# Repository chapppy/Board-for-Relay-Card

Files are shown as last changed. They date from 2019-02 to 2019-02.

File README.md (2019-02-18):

#  Board-for-Relay-Card
This repository contains design of schematic and PCB for Relay Card. 
**This board support**:
- up to 7 relays (with SPDT contacts)
- additional 7 relays on extra board
- control of relay over USB
- control of relay over CAN
- single power supply from USB
- possibility of external power supply (for board control over CAN)

This is based on STM32 microcontroller F0 family (STM32F072C8T6). This microcontroller supports USB and in advance it support crystal-less USB. The CAN driver is also available. 

The goal is use as less parts as possible with consideration of hand soldering. All the part should be simple to get or replace with another compatible. The design is simple two layer board with most of the parts (and all necessary) on top layer. The design fits to box for DIN lath.

This is related to these repositories:
[Firmware-for-Relay-Card](https://github.com/chapppy/Firmware-for-Relay-Card "Firmware-for-Relay-Card") 
[Sample-GUI-for-Relay-Card](https://github.com/chapppy/Sample-GUI-for-Relay-Card "Sample-GUI-for-Relay-Card")
[Board-for-Relay-Card](https://github.com/chapppy/Board-for-Relay-Card "Board-for-Relay-Card")

## schematic
[full schematic](https://github.com/chapppy/Board-for-Relay-Card/blob/master/export/schematic-full.pdf "full schematic")

In case of control only over USB and 4 relays, there is reduced schematic:
[reduced schematic](https://github.com/chapppy/Board-for-Relay-Card/blob/master/export/schematic-USB-4-rleays.pdf "reduced schematic")

## PCB design
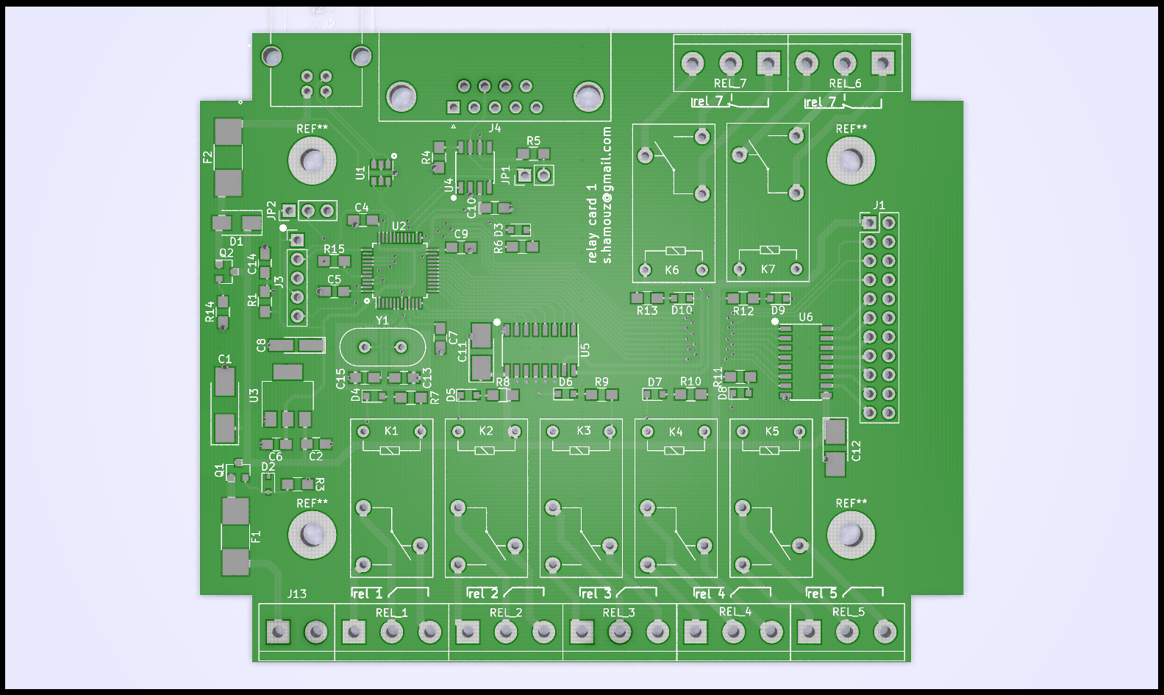
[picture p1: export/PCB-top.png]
PCB-top

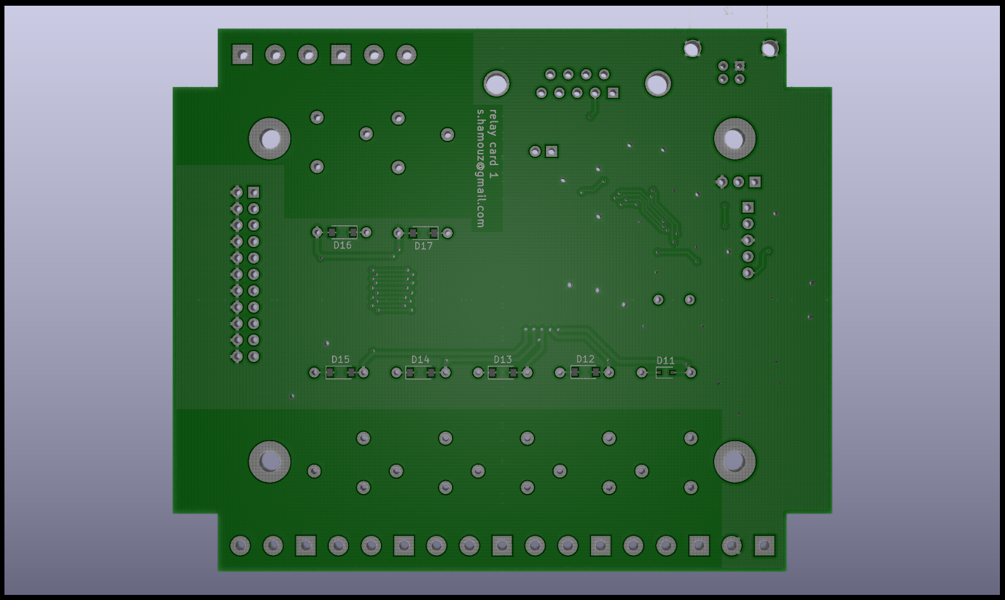
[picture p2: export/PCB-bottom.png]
PCB-bottom


## data for manufacturing
[manufacturing data](https://github.com/chapppy/Board-for-Relay-Card/blob/master/export/manufacturing.zip "manufacturing data")

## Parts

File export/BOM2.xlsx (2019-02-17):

quantity | Supplier ref | Link | Designation
8 | 1181041 | https://cz.farnell.com/omron/g5q-1eu-5dc/relay-spdt-250vac-30vdc-10a/dp/1181041 | G5SB-5V
2 | 2112373 | https://cz.farnell.com/multicomp/usb-b-s-ra/usb-2-0-type-b-receptacle-th/dp/2112373 | USB_B
8 | 1581242 | https://cz.farnell.com/multicomp/mcl-s270gc/led-0805-green-10mcd-570nm/dp/1581242 | LED
4 | 498737 | https://cz.farnell.com/avx/tajb106k016rnj/cap-10-f-16v-10-1210-smd/dp/498737 | 10uF/16V
2 | 2750643 | https://cz.farnell.com/stmicroelectronics/stm32f072c8t6/mcu-arm-cortex-m0-48mhz-lqfp-48/dp/2750643 | STM32F042C4Tx
2 | 2852737 | https://cz.farnell.com/avx/tajc476k016snj/cap-47-f-16v-10/dp/2852737 | 47uF/16V
2 | 2321203 | https://cz.farnell.com/kemet/t491a225k006at/cap-2-2-f-6-3v-10-1206/dp/2321203 | 2.2uF/6.3V
2 | 2317476 | https://cz.farnell.com/on-semiconductor/mm3z5v1st1g/diode-zener-5-1v-200mw-sod-323/dp/2317476 | 5v1
4 | 2468051 | https://cz.farnell.com/infineon/irlml2244trpbf/mosfet-p-ch-20v-4-3a-sot-23-3/dp/2468051 | IRLML6402TRPBF
2 | 1269406 | https://cz.farnell.com/stmicroelectronics/usblc6-2sc6/esd-protection-3-5pf-17v-sot23/dp/1269406 | USBLC6-2SC6
5 | 2510222 | https://cz.farnell.com/microchip/mic5205-3-3ym5-tr/ic-ldo-150ma-3-3v-ln-sot23-5/dp/2510222 | MIC5205-3.3
2 | 1842268 | https://cz.farnell.com/txc/9b-8-000maaj-b/xtal-8-000mhz-18pf-hc-49s/dp/1842268 | 8MHz
2 | 9907491 | https://cz.farnell.com/stmicroelectronics/stps1l30a/diode-schottky-1a-30v/dp/9907491 | STPS1L30A
4 | 2335704 | https://cz.farnell.com/texas-instruments/uln2003lvdr/relay-driver-sink-0-14a-soic-16/dp/2335704 | ULN2003A
2 | 1345924 | https://cz.farnell.com/littelfuse/minismdc075f-24-2/polyswitch-smd-1812-0-75a/dp/1345924 | SD110-16
2 | 1207268 | https://cz.farnell.com/texas-instruments/sn65hvd233dg4/transceiver-can-65hvd233-soic8/dp/1207268 | sn65hvd233
8 | 8734275 | https://cz.farnell.com/nexperia/bas316-115/diode-switching-250ma-100v-sod/dp/8734275 | D
2 | 2980894 | https://cz.farnell.com/stmicroelectronics/stm32g071gbu6/mcu-32bit-64mhz-ufqfpn-28/dp/2980894 | STM32G071GBU6

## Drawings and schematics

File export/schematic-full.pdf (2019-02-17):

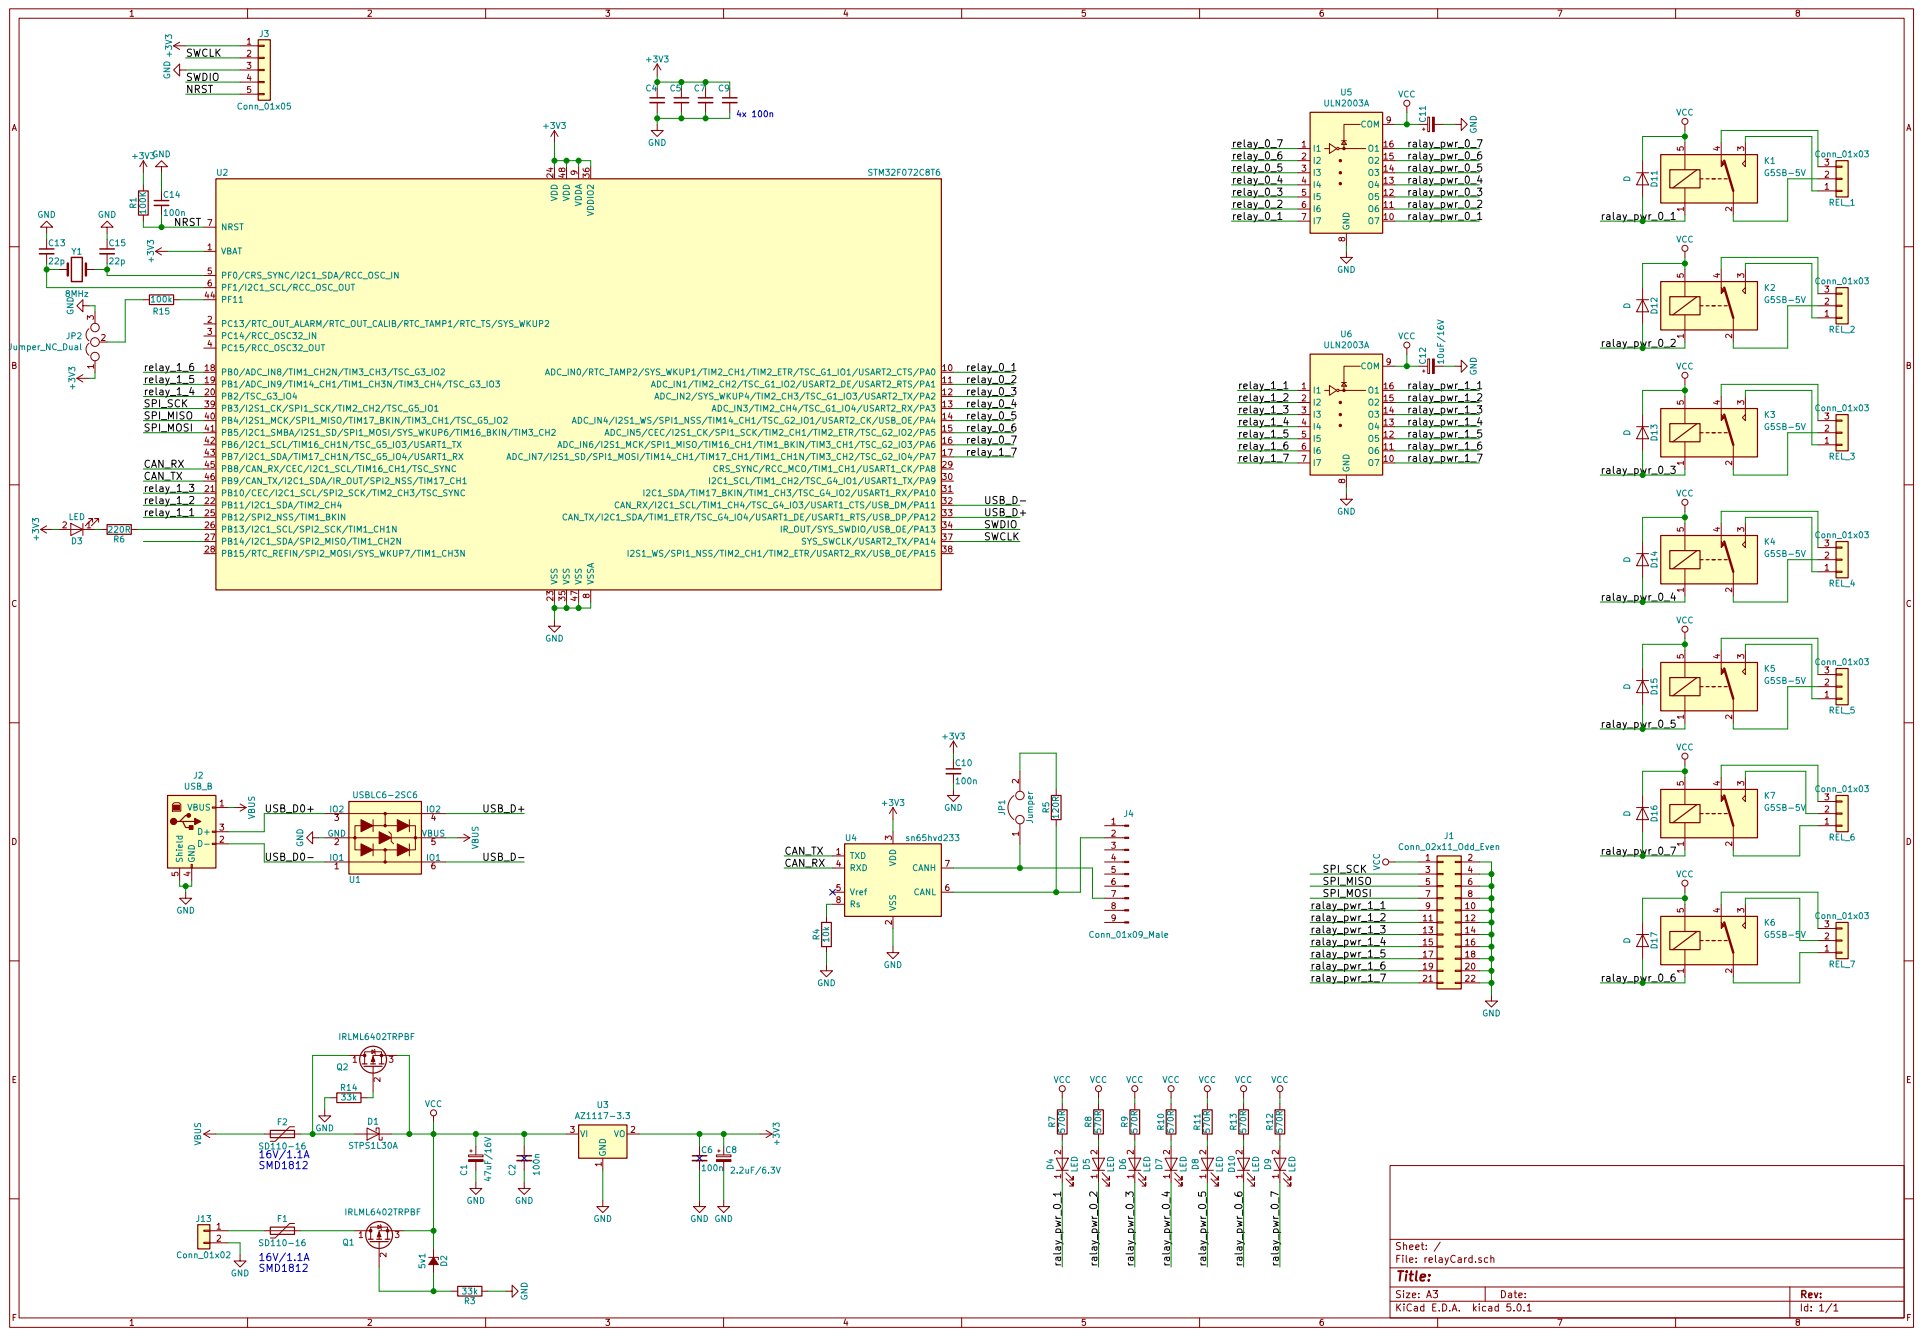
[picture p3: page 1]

File: relayCard.sch Sheet: /

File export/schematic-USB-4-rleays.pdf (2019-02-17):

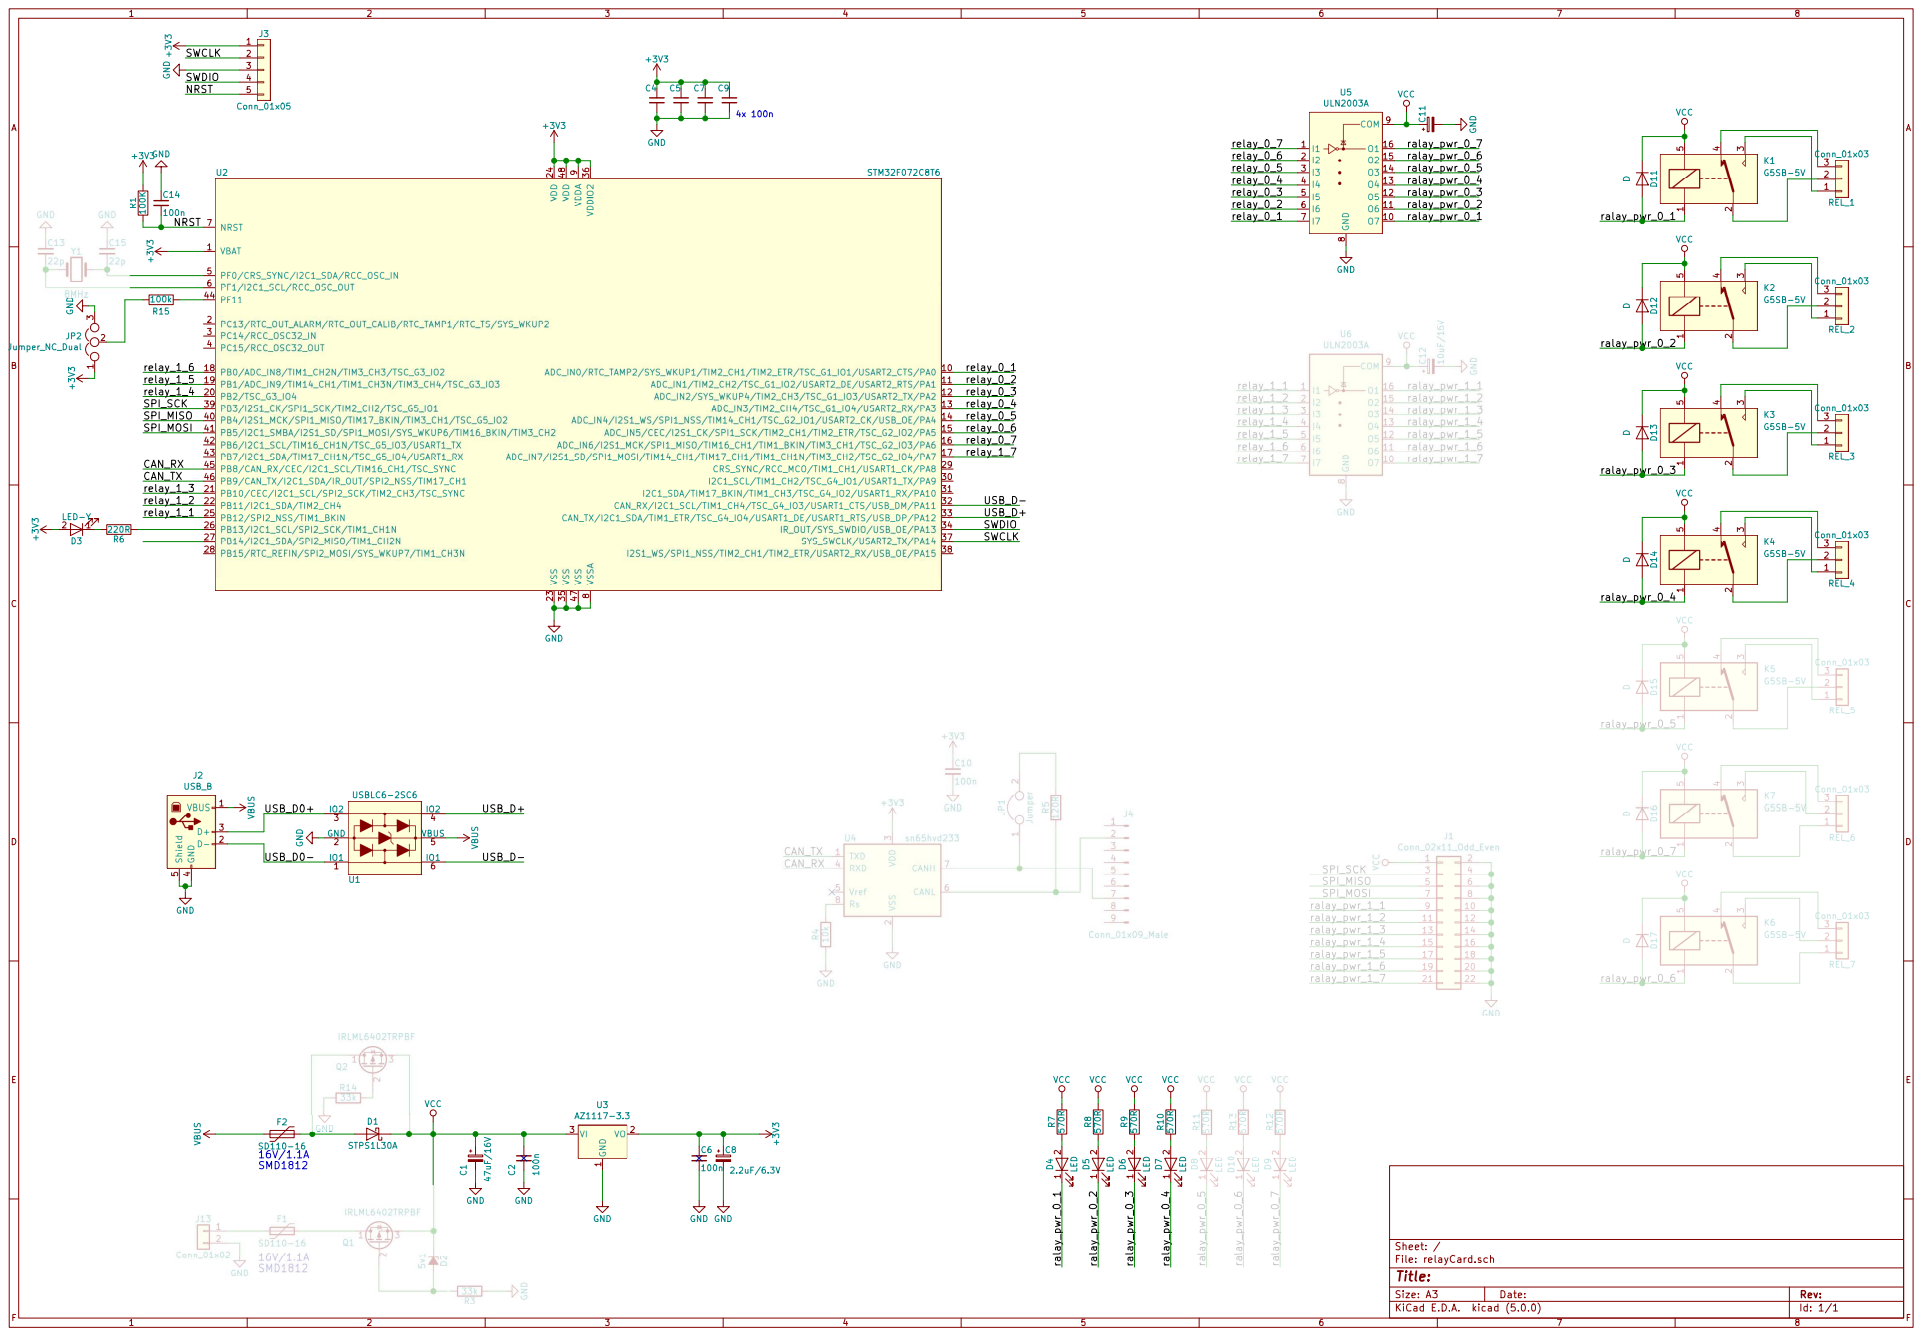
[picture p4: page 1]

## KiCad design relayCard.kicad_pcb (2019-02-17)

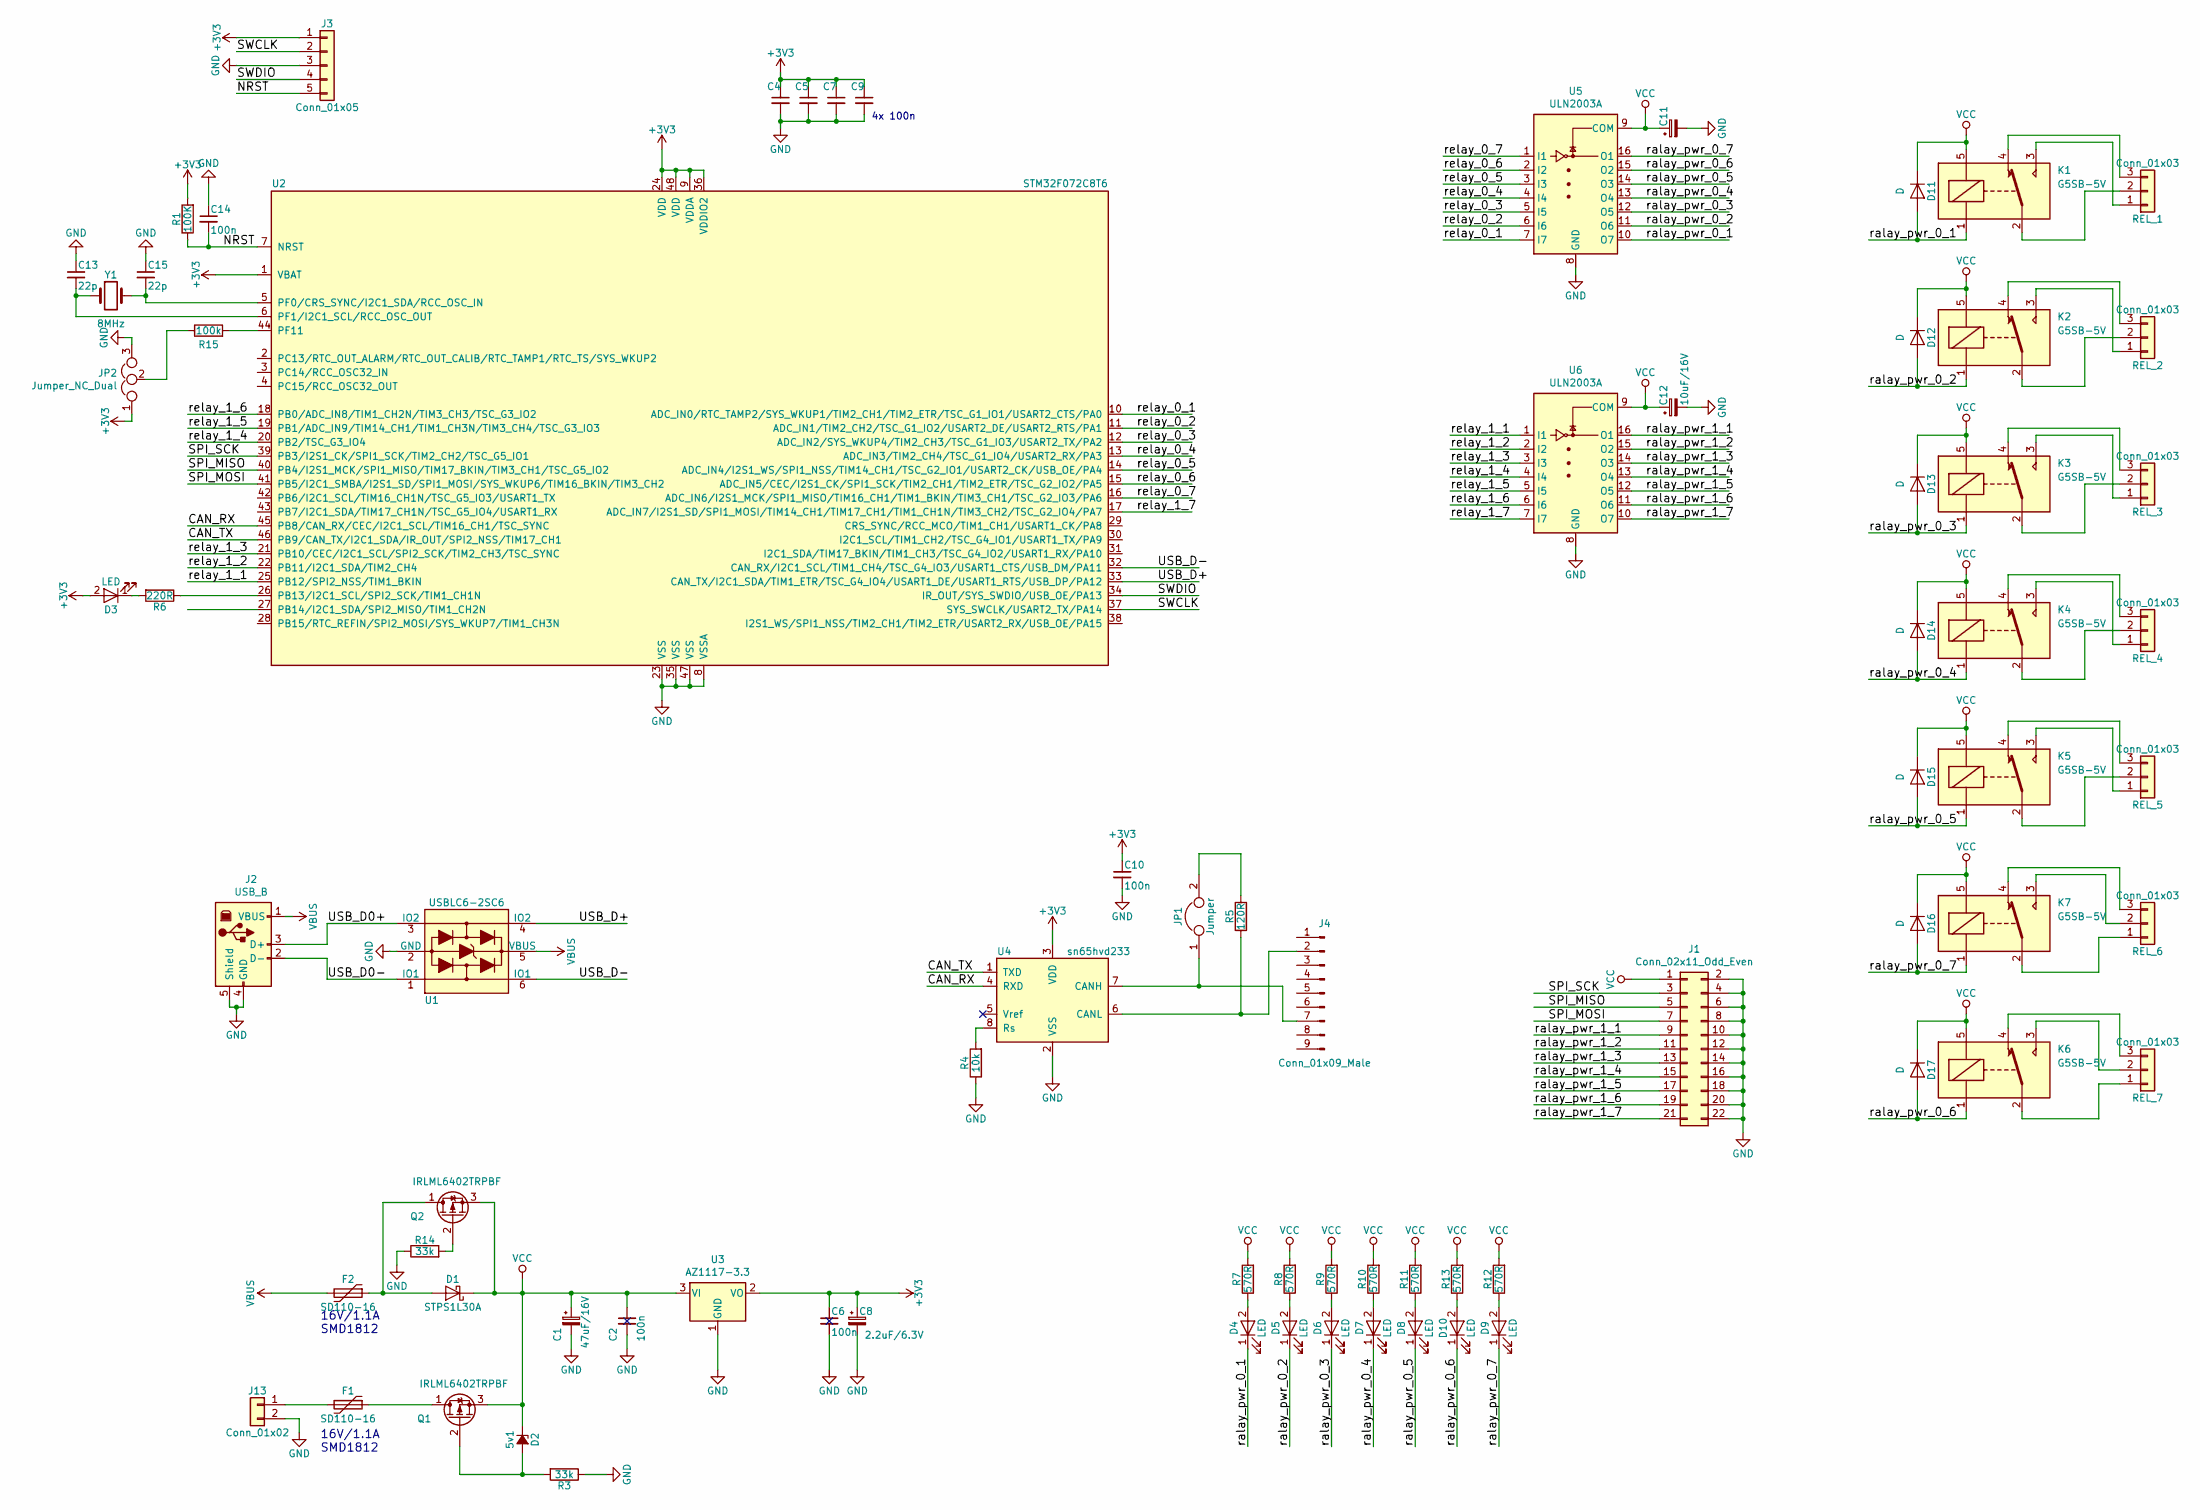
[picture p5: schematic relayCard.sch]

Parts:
C1: 47uF/16V; CP_Tantalum_Case-C_EIA-6032-28_Hand
C2, C4, C5, C6, C7, C9, C10, C14: 100n; C_0805_HandSoldering
C8: 2.2uF/6.3V; CP_Tantalum_Case-A_EIA-3216-18_Hand
C11, C12: 10uF/16V; CP_Tantalum_Case-B_EIA-3528-21_Hand
C13, C15: 22p; C_0805_HandSoldering
D1: STPS1L30A; D_SMA
D2: 5v1; D_SOD-323
D3, D4, D5, D6, D7, D8, D9, D10: LED; D_0805
D11: D; D_SOD-323
D12, D13, D14, D15, D16, D17: D; D_SOD-123
F1, F2: SD110-16; R_1812_HandSoldering
J1: Conn_02x11_Odd_Even; Pin_Header_Straight_2x11_Pitch2.54mm
J2: USB_B
J3: Conn_01x05; Pin_Header_Straight_1x05_Pitch2.54mm
J4: Conn_01x09_Male; DSUB-9_Female_Horizontal_Pitch2.77x2.84mm_EdgePinOffset7.70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
J13: Conn_01x02; TerminalBlock_bornier-2_P5.08mm
JP1: Jumper; Pin_Header_Straight_1x02_Pitch2.54mm
JP2: Jumper_NC_Dual; Pin_Header_Straight_1x03_Pitch2.54mm
K1, K2, K3, K4, K5, K6, K7: G5SB-5V; Relay_SPDT_OMRON-G5Q
Q1, Q2: IRLML6402TRPBF; SOT-23
R1: 100K; R_0805_HandSoldering
R3, R14: 33k; R_0805_HandSoldering
R4: 10k; R_0805_HandSoldering
R5: 120R; R_0805_HandSoldering
R6: 220R; R_0805_HandSoldering
R7, R8, R9, R10, R11, R12, R13: 570R; R_0805_HandSoldering
R15: 100k; R_0805_HandSoldering
REL_1, REL_2, REL_3, REL_4, REL_5, REL_6, REL_7: Conn_01x03; TerminalBlock_bornier-3_P5.08mm
U1: USBLC6-2SC6; SOT-23-6
U2: STM32F072C8T6; LQFP-48_7x7mm_Pitch0.5mm
U3: AZ1117-3.3; SOT-223
U4: sn65hvd233; SOIC-8_3.9x4.9mm_Pitch1.27mm
U5, U6: ULN2003A; SOIC-16_3.9x9.9mm_Pitch1.27mm
Y1: 8MHz; Crystal_HC49-4H_Vertical

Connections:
+3V3: C4.1, C5.1, C6.1, C7.1, C8.1, C9.1, C10.1, D3.2 (A), J3.1, JP2.1, R1.2, U2.1 (VBAT), U2.9 (VDDA), U2.24 (VDD), U2.36 (VDDIO2), U2.48 (VDD), U3.2 (VO), U4.3 (VDD)
/CAN_RX: U2.45 (PB8/CAN_RX/CEC/I2C1_SCL/TIM16_CH1/TSC_S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), U4.4 (RXD)
/CAN_TX: U2.46 (PB9/CAN_TX/I2C1_SDA/IR_OUT/SPI2_NSS/TIM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), U4.1 (TXD)
/NRST: C14.2, J3.5, R1.1, U2.7 (NRST)
/SPI_MISO: J1.5, U2.40 (PB4/I2S1_MCK/SPI1_MISO/TIM17_BKIN/TIM3_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)
/SPI_MOSI: J1.7, U2.41 (PB5/I2C1_SMBA/I2S1_SD/SPI1_MOSI/SYS_WKU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)
/SPI_SCK: J1.3, U2.39 (PB3/I2S1_CK/SPI1_SCK/TIM2_CH2/TSC_G5_IO1)
/SWCLK: J3.2, U2.37 (SYS_SWCLK/USART2_TX/PA14)
/SWDIO: J3.4, U2.34 (IR_OUT/SYS_SWDIO/USB_OE/PA13)
/USB_D0+: J2.3 (D+), U1.3 (IO2)
/USB_D0-: J2.2 (D-), U1.1 (IO1)
/USB_D+: U1.4 (IO2), U2.33 (CAN_TX/I2C1_SDA/TIM1_ETR/TSC_G4_IO4/USA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)
/USB_D-: U1.6 (IO1), U2.32 (CAN_RX/I2C1_SCL/TIM1_CH4/TSC_G4_IO3/USA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)
/ralay_pwr_0_1: D4.1 (K), D11.2 (A), K1.1, U5.10 (O7)
/ralay_pwr_0_2: D5.1 (K), D12.2 (A), K2.1, U5.11 (O6)
/ralay_pwr_0_3: D6.1 (K), D13.2 (A), K3.1, U5.12 (O5)
/ralay_pwr_0_4: D7.1 (K), D14.2 (A), K4.1, U5.13 (O4)
/ralay_pwr_0_5: D8.1 (K), D15.2 (A), K5.1, U5.14 (O3)
/ralay_pwr_0_6: D10.1 (K), D17.2 (A), K6.1, U5.15 (O2)
/ralay_pwr_0_7: D9.1 (K), D16.2 (A), K7.1, U5.16 (O1)
/ralay_pwr_1_1: J1.9, U6.16 (O1)
/ralay_pwr_1_2: J1.11, U6.15 (O2)
/ralay_pwr_1_3: J1.13, U6.14 (O3)
/ralay_pwr_1_4: J1.15, U6.13 (O4)
/ralay_pwr_1_5: J1.17, U6.12 (O5)
/ralay_pwr_1_6: J1.19, U6.11 (O6)
/ralay_pwr_1_7: J1.21, U6.10 (O7)
/relay_0_1: U2.10 (ADC_IN0/RTC_TAMP2/SYS_WKUP1/TIM2_CH1/TI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), U5.7 (I7)
/relay_0_2: U2.11 (ADC_IN1/TIM2_CH2/TSC_G1_IO2/USART2_DE/U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), U5.6 (I6)
/relay_0_3: U2.12 (ADC_IN2/SYS_WKUP4/TIM2_CH3/TSC_G1_IO3/U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), U5.5 (I5)
/relay_0_4: U2.13 (ADC_IN3/TIM2_CH4/TSC_G1_IO4/USART2_RX/P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), U5.4 (I4)
/relay_0_5: U2.14 (ADC_IN4/I2S1_WS/SPI1_NSS/TIM14_CH1/TSC_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), U5.3 (I3)
/relay_0_6: U2.15 (ADC_IN5/CEC/I2S1_CK/SPI1_SCK/TIM2_CH1/T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), U5.2 (I2)
/relay_0_7: U2.16 (ADC_IN6/I2S1_MCK/SPI1_MISO/TIM16_CH1/TI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), U5.1 (I1)
/relay_1_1: U2.25 (PB12/SPI2_NSS/TIM1_BKIN), U6.1 (I1)
/relay_1_2: U2.22 (PB11/I2C1_SDA/TIM2_CH4), U6.2 (I2)
/relay_1_3: U2.21 (PB10/CEC/I2C1_SCL/SPI2_SCK/TIM2_CH3/TSC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), U6.3 (I3)
/relay_1_4: U2.20 (PB2/TSC_G3_IO4), U6.4 (I4)
/relay_1_5: U2.19 (PB1/ADC_IN9/TIM14_CH1/TIM1_CH3N/TIM3_CH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), U6.5 (I5)
/relay_1_6: U2.18 (PB0/ADC_IN8/TIM1_CH2N/TIM3_CH3/TSC_G3_I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), U6.6 (I6)
/relay_1_7: U2.17 (ADC_IN7/I2S1_SD/SPI1_MOSI/TIM14_CH1/TIM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), U6.7 (I7)
GND: C1.2, C2.2, C4.2, C5.2, C6.2, C7.2, C8.2, C9.2, C10.2, C11.2, C12.2, C13.1, C14.1, C15.1, J1.2, J1.4, J1.6, J1.8, J1.10, J1.12, J1.14, J1.16, J1.18, J1.20, J1.22, J2.4 (GND), J2.5 (Shield), J3.3, J13.2, JP2.3, R3.1, R4.1, R14.1, U1.2 (GND), U2.8 (VSSA), U2.23 (VSS), U2.35 (VSS), U2.47 (VSS), U3.1 (GND), U4.2 (VSS), U5.8 (GND), U6.8 (GND)
unnamed: C13.2, U2.6 (PF1/I2C1_SCL/RCC_OSC_OUT), Y1.1
unnamed: C15.2, U2.5 (PF0/CRS_SYNC/I2C1_SDA/RCC_OSC_IN), Y1.2
unnamed: D1.2 (A), F2.1, Q2.1 (D)
unnamed: D2.2 (A), Q1.2 (G), R3.2
unnamed: D3.1 (K), R6.2
unnamed: D4.2 (A), R7.1
unnamed: D5.2 (A), R8.1
unnamed: D6.2 (A), R9.1
unnamed: D7.2 (A), R10.1
unnamed: D8.2 (A), R11.1
unnamed: D9.2 (A), R12.1
unnamed: D10.2 (A), R13.1
unnamed: F1.1, Q1.1 (D)
unnamed: F1.2, J13.1
unnamed: J4.2, R5.1, U4.6 (CANL)
unnamed: J4.7, JP1.1, U4.7 (CANH)
unnamed: JP1.2, R5.2
unnamed: JP2.2, R15.1
unnamed: K1.2, REL_1.2
unnamed: K1.3, REL_1.1
unnamed: K1.4, REL_1.3
unnamed: K2.2, REL_2.2
unnamed: K2.3, REL_2.1
unnamed: K2.4, REL_2.3
unnamed: K3.2, REL_3.2
unnamed: K3.3, REL_3.1
unnamed: K3.4, REL_3.3
unnamed: K4.2, REL_4.2
unnamed: K4.3, REL_4.1
unnamed: K4.4, REL_4.3
unnamed: K5.2, REL_5.2
unnamed: K5.3, REL_5.1
unnamed: K5.4, REL_5.3
unnamed: K6.2, REL_7.1
unnamed: K6.3, REL_7.2
unnamed: K6.4, REL_7.3
unnamed: K7.2, REL_6.1
unnamed: K7.3, REL_6.2
unnamed: K7.4, REL_6.3
unnamed: Q2.2 (G), R14.2
unnamed: R4.2, U4.8 (Rs)
unnamed: R6.1, U2.26 (PB13/I2C1_SCL/SPI2_SCK/TIM1_CH1N)
unnamed: R15.2, U2.44 (PF11)
VBUS: F2.2, J2.1 (VBUS), U1.5 (VBUS)
VCC: C1.1, C2.1, C11.1, C12.1, D1.1 (K), D2.1 (K), D11.1 (K), D12.1 (K), D13.1 (K), D14.1 (K), D15.1 (K), D16.1 (K), D17.1 (K), J1.1, K1.5, K2.5, K3.5, K4.5, K5.5, K6.5, K7.5, Q1.3 (S), Q2.3 (S), R7.2, R8.2, R9.2, R10.2, R11.2, R12.2, R13.2, U3.3 (VI), U5.9 (COM), U6.9 (COM)

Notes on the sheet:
16V/1.1A SMD1812
4x 100n

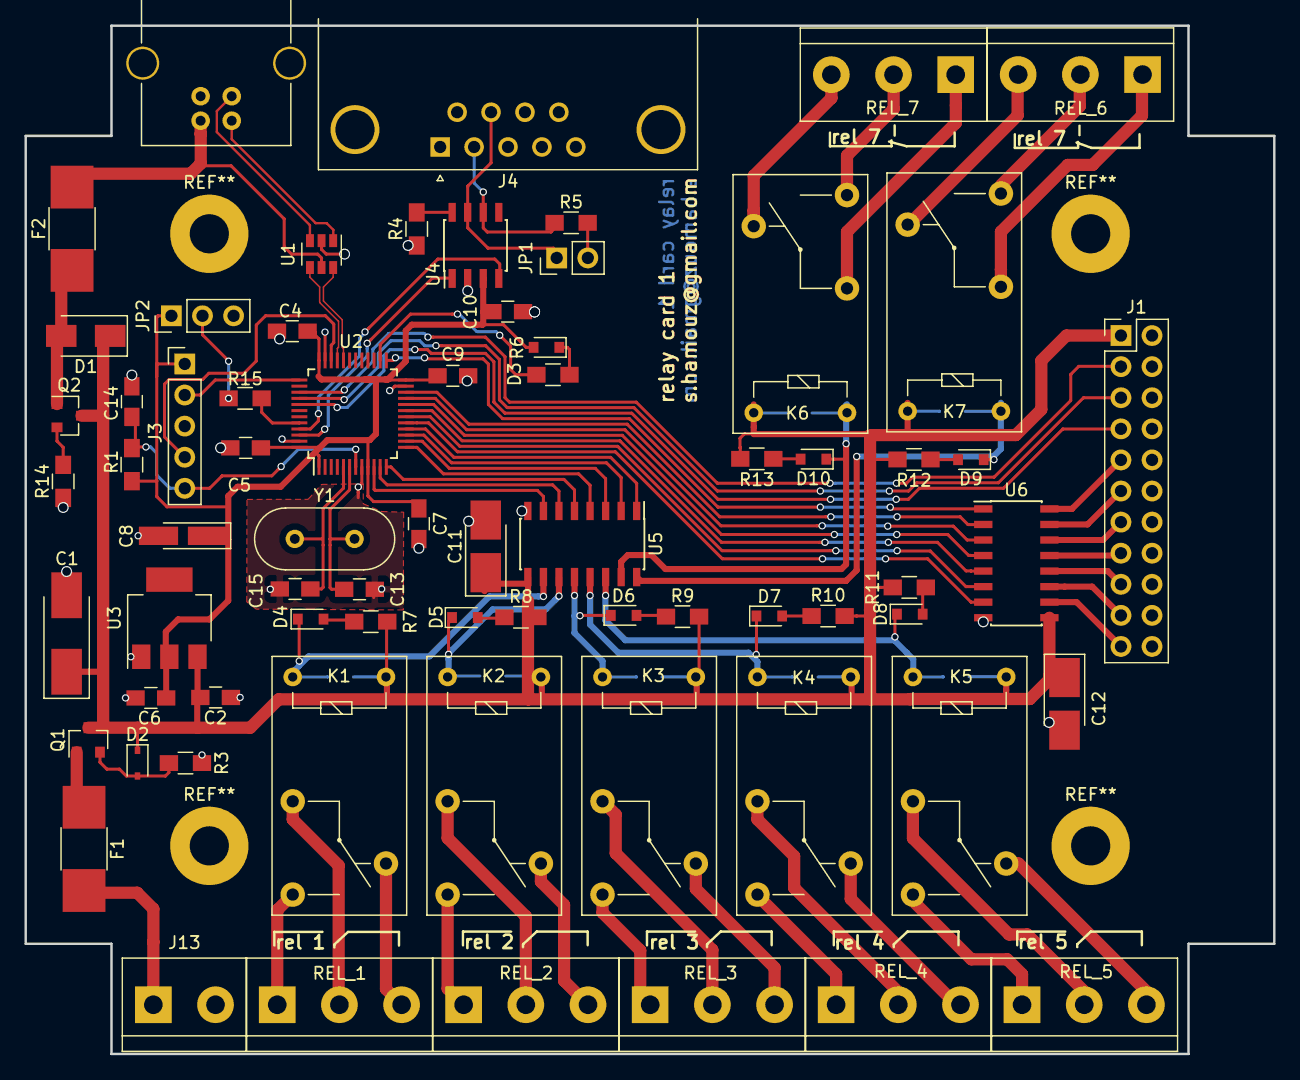
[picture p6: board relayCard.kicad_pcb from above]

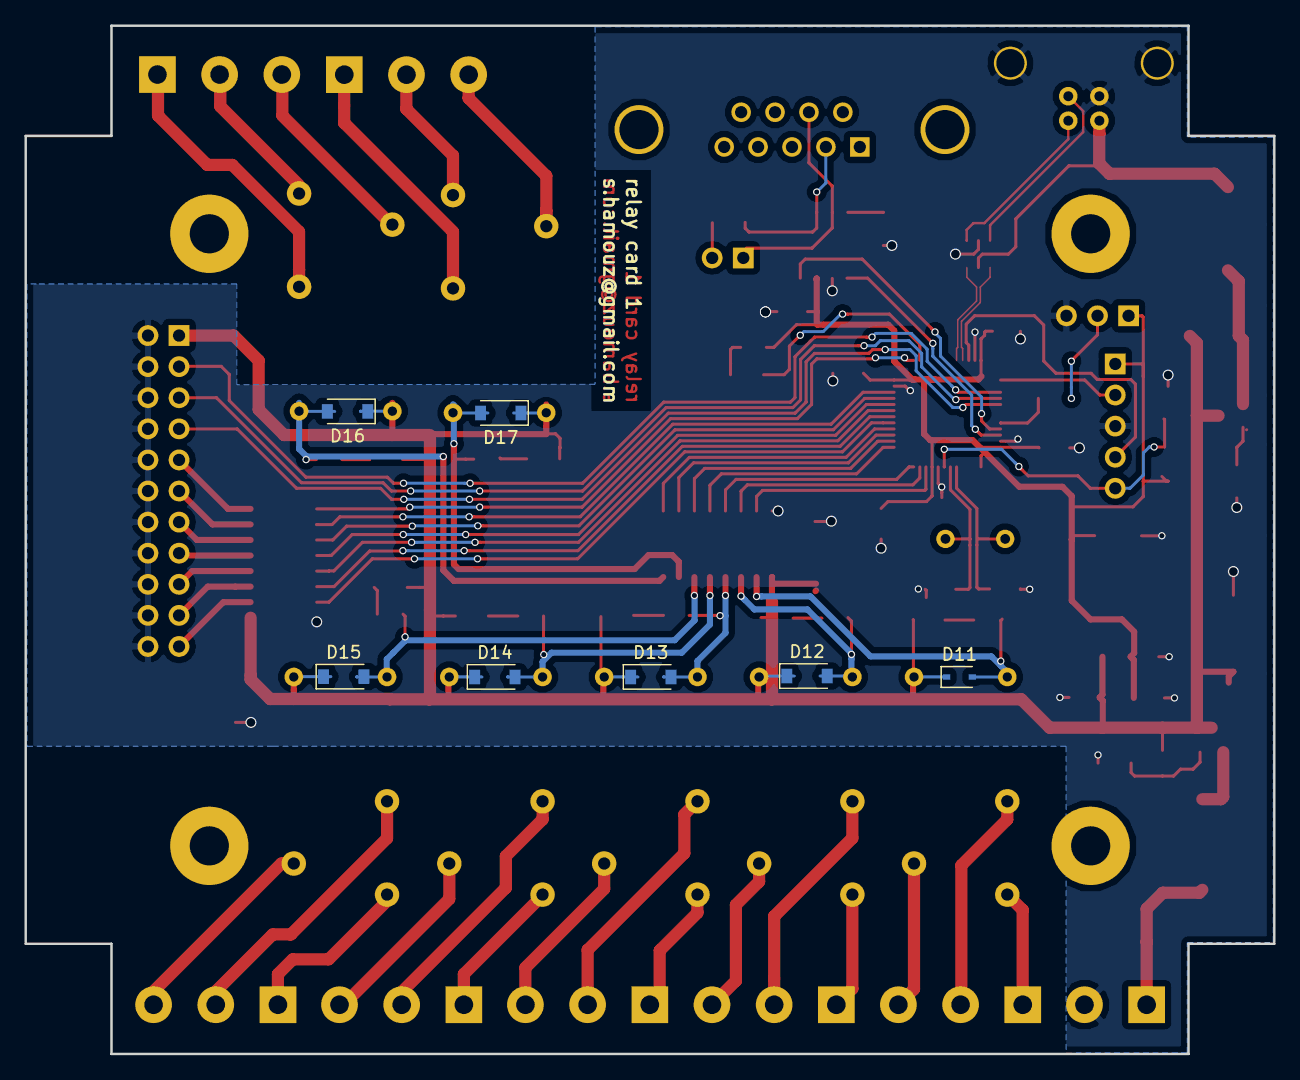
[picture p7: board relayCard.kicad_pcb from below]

Board: 2 copper layers, 102.0 x 84.0 mm, 77 parts (7 on the bottom side), 87 nets.
